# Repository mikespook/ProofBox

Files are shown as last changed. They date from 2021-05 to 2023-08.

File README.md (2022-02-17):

# TinyProofBox

An Arduino Nano based, (TODO: TinyGo implemented) sourdough proof box with LCD display

# Tools

[FreeCAD][freecad]
[KiCAD][kicad]
[Arduino IDE][ide]
TODO: [TinyGo][tinygo]

# Parts

[Arduino Nano][nano]
[DHT11][dht11] sensor
[LCD1602][lcd1602] with I2C adaptor
2 channel relay module
12V 40W Heater (diameter: 6mm, length: 20mm)
12V 4010 cooling fan
Heat sink (length: 36mm, height: 36mm, width: 35)
Prototype board (length: 70mm, width: 50mm)

[freecad]: https://www.freecadweb.org
[kicad]: https://www.kicad.org
[tinygo]: https://tinygo.org
[dht11]: https://create.arduino.cc/projecthub/search?q=DHT11
[lcd1602]: https://create.arduino.cc/projecthub/search?q=lcd1602+i2c
[nano]: https://www.arduino.cc/en/pmwiki.php?n=Main/ArduinoBoardNano
[ide]: https://www.arduino.cc/en/software

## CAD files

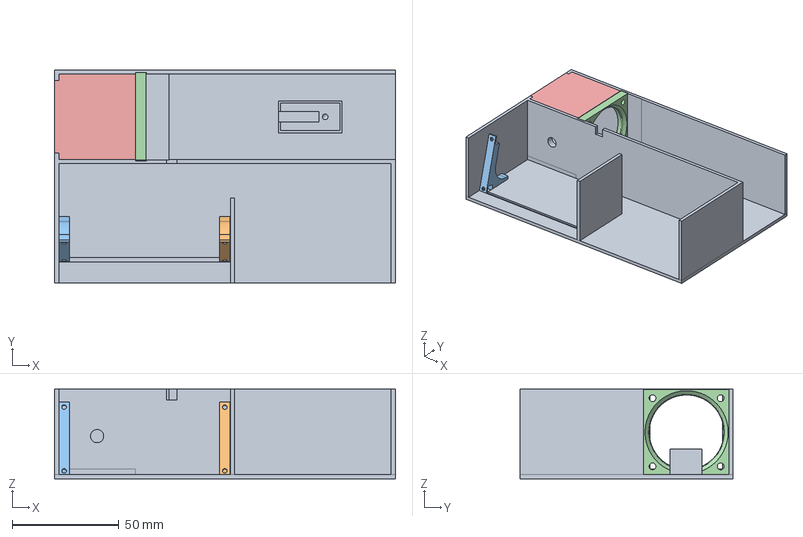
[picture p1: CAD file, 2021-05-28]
FreeCAD/ProofBox-assembled.FCStd
160.0 x 100.0 x 42.0 mm
ProofBox-parts_Base_001
ProofBox-parts_LCD stand_002
ProofBox-parts_LCD stand_001
ProofBox-parts_Fan holder_001
ProofBox-parts_Heat sink cover_001

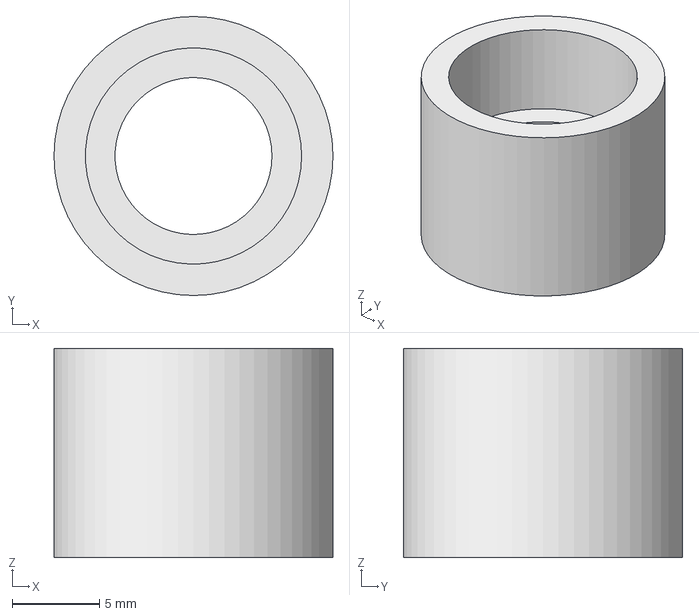
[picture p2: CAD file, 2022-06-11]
FreeCAD/ProofBox-parts.FCStd
16.0 x 16.0 x 12.0 mm

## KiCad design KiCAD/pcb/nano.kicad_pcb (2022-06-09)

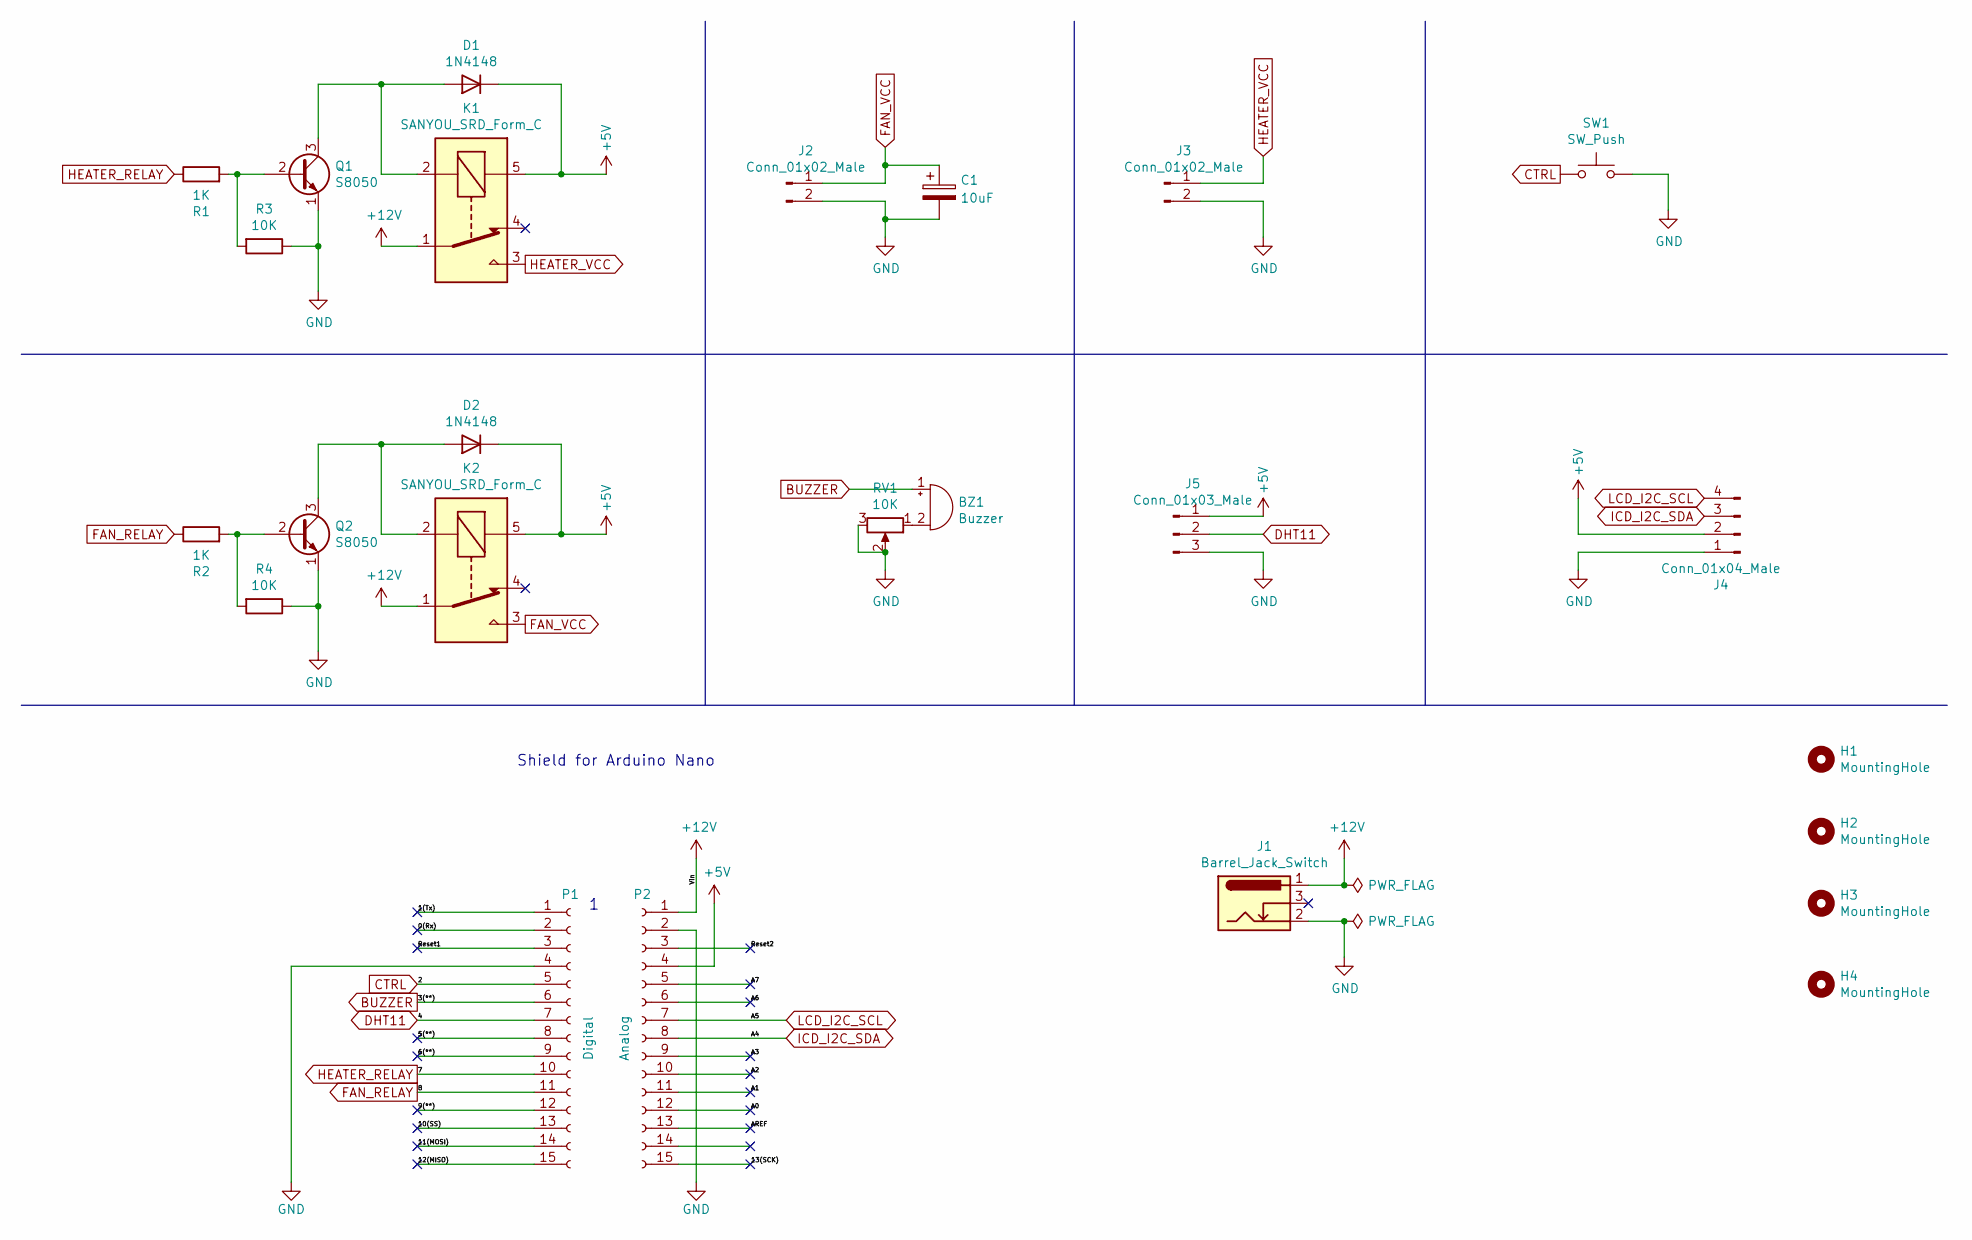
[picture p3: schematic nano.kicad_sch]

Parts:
BZ1: Buzzer; Buzzer_12x9.5RM7.6
C1: 10uF; CP_Radial_D5.0mm_P2.00mm
D1, D2: 1N4148; D_DO-35_SOD27_P7.62mm_Horizontal
H1, H2, H3, H4: MountingHole; MountingHole_2.2mm_M2
J1: Barrel_Jack_Switch; BarrelJack_Horizontal
J2, J3: Conn_01x02_Male; JST_XH_B2B-XH-AM_1x02_P2.50mm_Vertical
J4: Conn_01x04_Male; PinHeader_1x04_P2.54mm_Vertical
J5: Conn_01x03_Male; PinHeader_1x03_P2.54mm_Vertical
K1, K2: SANYOU_SRD_Form_C; Relay_SPDT_SANYOU_SRD_Series_Form_C
P1: Digital; PinSocket_1x15_P2.54mm_Vertical
P2: Analog; PinSocket_1x15_P2.54mm_Vertical
Q1, Q2: S8050; TO-92_Inline
R1, R2: 1K; R_Axial_DIN0204_L3.6mm_D1.6mm_P7.62mm_Horizontal
R3, R4: 10K; R_Axial_DIN0204_L3.6mm_D1.6mm_P7.62mm_Horizontal
RV1: 10K; Potentiometer_Runtron_RM-065_Vertical
SW1: SW_Push; SW_PUSH_6mm

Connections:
+5V: D1.1 (K), D2.1 (K), J4.2, J5.1, K1.5, K2.5, P2.4
+12V: J1.1, K1.1, K2.1, P2.1
/0(Rx): P1.2
/1(Tx): P1.1
/5(**): P1.8
/6(**): P1.9
/9(**): P1.12
/10(SS): P1.13
/11(MOSI): P1.14
/12(MISO): P1.15
/13(SCK): P2.15
/A0: P2.12
/A1: P2.11
/A2: P2.10
/A3: P2.9
/A6: P2.6
/A7: P2.5
/AREF: P2.13
/Reset1: P1.3
/Reset2: P2.3
BUZZER: BZ1.1 (-), P1.6
CTRL: P1.5, SW1.1
DHT11: J5.2, P1.7
FAN_RELAY: P1.11, R2.1
FAN_VCC: C1.1, J2.1, K2.3
GND: C1.2, J1.2, J2.2, J3.2, J4.1, J5.3, P1.4, P2.2, Q1.1 (E), Q2.1 (E), R3.1, R4.1, RV1.2, RV1.3, SW1.2
HEATER_RELAY: P1.10, R1.1
HEATER_VCC: J3.1, K1.3
ICD_I2C_SDA: J4.3, P2.8
LCD_I2C_SCL: J4.4, P2.7
unnamed: BZ1.2 (+), RV1.1
unnamed: D1.2 (A), K1.2, Q1.3 (C)
unnamed: D2.2 (A), K2.2, Q2.3 (C)
unnamed: Q1.2 (B), R1.2, R3.2
unnamed: Q2.2 (B), R2.2, R4.2

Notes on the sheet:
Shield for Arduino Nano

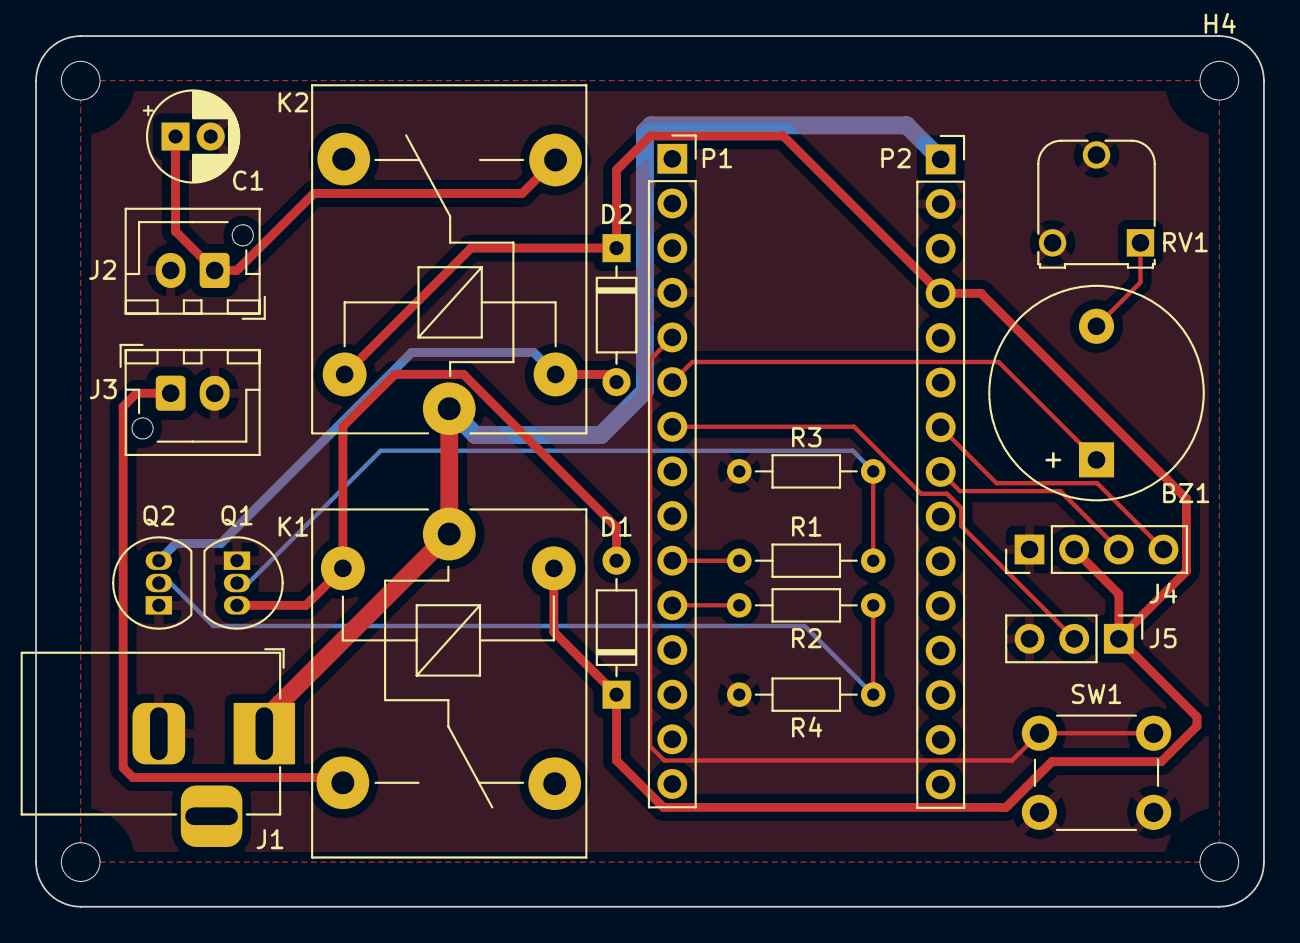
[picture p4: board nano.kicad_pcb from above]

Board: 2 copper layers, 69.8 x 49.5 mm, 25 parts (0 on the bottom side), 17 nets.

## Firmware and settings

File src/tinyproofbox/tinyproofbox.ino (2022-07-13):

#include <avr/wdt.h>

#include "ProofBox.h"
#include "Button.h"
#include "Buzzer.h"
#include "LCD.h"

#define SERIAL_SPEED 115200

float t, h;

void setup() {
	Serial.begin(SERIAL_SPEED);
	while(!Serial) {}
	Serial.println();
	Serial.print("Serial speed: ");
	Serial.println(SERIAL_SPEED);
	Button.begin();
	Buzzer.begin();
	Buzzer.on();
	LCD.begin();
	LCD.clear();
	LCD.backlight();
	delay(100);
	ProofBox.begin();
	state(ProofBox.current());
	delay(2000);
	wdt_enable(WDTO_500MS);
}

void state(int n) {
	char text[17];
	switch(n) {
		case 0:
			sprintf(text, "Off  [520.co.nz]");
			break;
		case 1:
			sprintf(text, "Starter[%d-%d%cC]", ProofBoxClass::StarterMin, ProofBoxClass::StarterMax, 0xDF);	
			break;
		case 2:
			sprintf(text, "Proof1 [%d-%d%cC]", ProofBoxClass::Proof1Min, ProofBoxClass::Proof1Max, 0xDF);	
			break;
		case 3:
			sprintf(text, "Proof2 [%d-%d%cC]", ProofBoxClass::Proof2Min, ProofBoxClass::Proof2Max, 0xDF);
			break;
	}
	LCD.output(text);
}

void loop() {
	wdt_reset();
	LCD.autoBacklight();
	if (Button.pressed()) {
		// turn on LCD
		LCD.backlight();
		uint8_t c = Button.countdown();
		if (0 == c) {
			switch(ProofBox.next()) {
				case 0:
					Buzzer.off();
					break;
				case 1:
					Buzzer.starter();
					break;
				case 2:
					Buzzer.proof1();
					break;
				case 3:
					Buzzer.proof2();
					break;
			}
			Serial.println("OK1");
			Button.ended();
			Serial.println("OK2");	
			return;
		}
		LCD.holding(c);
		return;
	}
	state(ProofBox.current());
	if (ProofBox.loop(&t, &h)) {
		LCD.output(t, h);
	} else {
		LCD.error();
	}
}

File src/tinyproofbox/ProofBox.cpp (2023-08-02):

#include "ProofBox.h"

void ProofBoxClass::begin() {
	int now = millis();
	dht = new DHT(PinDHT, DHT11);
	dht->begin();
	program = EEPROM.read(0);
	dht->readTemperature();
	dht->readHumidity();
}

bool ProofBoxClass::loop(float *t, float *h) {
	uint32_t now = millis();

	if (now < lastNow) {
		nextHeatOn = 0;
		nextHeatOff = 0;
	}
	lastNow = now;

	if (Heater.isOn()) {
		nextFanOff = now + FanTick;
	}
	// fan is controlled separatly
	if (now < nextFanOff) {
		Fan.on();
	} else if (Fan.isOn()){
		this->debug("Fan off", *t, *h);
		Fan.off();
		Heater.off();
	}

	*t = dht->readTemperature();
	*h = dht->readHumidity();
	if (isnan(*h) || isnan(*t)) {
		// failure from sensor
		this->debug("Faulty sensor", *t, *h);
		Heater.off();
		nextFanOff = now + FanTick * 10;
		nextHeatOn = now + FanTick * 30;
		nextHeatOff = now + FanTick *10;	
		return false;
	}

	if (DeathMax < (*t)) {
		this->debug("Death temperature", *t, *h);
		Heater.off();
		nextFanOff = now + FanTick * 10;
		nextHeatOn = now + FanTick * 30;
		nextHeatOff = now + FanTick *10;
		return true;
	}

	float min, max;
	switch(program) {
		case StateStarter:
			min = StarterMin;
			max = StarterMax;
			break;
		case StateProof1:
			min = Proof1Min;
			max = Proof1Max;
			break;
		case StateProof2:
			min = Proof2Min;
			max = Proof2Max;
			break;
		default:
			Heater.off();
			return true;
	}

	if (max <= (*t)) { // too high
		Heater.off();
		this->debug("Over heating", *t, *h);
		nextFanOff = now + FanTick;
		return true;
	}
	if ((min <= (*t)) && ((*t) < max)) {
		Heater.off();
		this->debug("Target reached", *t, *h);
		return true;
	}

	// off period
	if ((*t) < min && nextHeatOff <= now && Heater.isOn()) {
		Heater.off();
		this->debug("Heater off", *t, *h);
		nextHeatOn = now + offTick(*t, min);
		nextHeatOff = nextHeatOn + onTick(*t, min);
		return true;
	}

	// on period
	if ((*t) < min && nextHeatOn <= now && !Heater.isOn()) {
		Fan.on();
		delay(100);
		Heater.on();
		nextHeatOff = now + onTick(*t, min);
		nextHeatOn = nextHeatOff + offTick(*t, min);
		this->debug("Heater & fan on", *t, *h);
		return true;
	}
	return true;
}

uint32_t ProofBoxClass::onTick(float current, float target) {
	float t = target - current;
	t = t < 0 ? 0 : t;
	return round(pow(HeatOnTickBase, t / 10) * HeatOnTickAdjust);
}

uint32_t ProofBoxClass::offTick(float current, float target) {
	float t = target - current;
	t = t < 0 ? 0 : t; 
	return round(pow(HeatOffTickBase, -t / 10) * HeatOffTickAdjust);
}

uint8_t ProofBoxClass::next() {
	program ++;
	if (program > StateProof2) program = StateOff;
	EEPROM.write(0, program);
	return program;
}

void ProofBoxClass::debug(const char* msg, float t, float h) {
	debug(msg, t, h, true);
}

void ProofBoxClass::debug(const char* msg, float t, float h, bool cached) {
	if (cached) {
		if ((strcmp(msg, lastMsg) == 0) && ((t - lastT) < 0.00001) &&
				((h - lastH) < 0.00001)) {
			return;
		}
		lastT = t;
		lastH = h;
		lastMsg = msg;
	}

	char buf[16];
	sprintf(buf, "%010lu", lastNow);
	Serial.print(buf);
	Serial.print("\tHeader on at: ");
	sprintf(buf, "%010lu", nextHeatOn);
	Serial.print(buf);
	Serial.print("\tFan off at: ");
	sprintf(buf, "%010lu", nextFanOff);	
	Serial.print(buf);
	Serial.print("\tT: ");
	Serial.print(t);
	Serial.print("°C\tH: ");
	Serial.print(h);
	Serial.print("%\t");
	Serial.println(msg);
}

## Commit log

2021-05-18 added parts
    [ProofBox-parts.FCStd]
2021-05-19 update LCD stand
    [ProofBox-parts.FCStd]
2021-05-25 heat sink & fan holders
    [ProofBox-parts.FCStd]
2021-05-26 added base
    [ProofBox-parts.FCStd]
2021-05-26 added assembled
    [ProofBox-assembled.FCStd]
2021-05-27 base design
    [ProofBox-assembled.FCStd, ProofBox-parts.FCStd]
2021-05-28 restructure base
    [ProofBox-assembled.FCStd, ProofBox-parts.FCStd]
2021-06-15 init arduino firmware
2021-06-23 added PCB board
    [nano.kicad_pcb, nano.sch]
2021-06-24 reroute wires
    [nano.kicad_pcb]
2021-06-24 split PCB and prototype board
    [nano.kicad_pcb, nano.sch]
2021-06-24 prototype board
    [nano.kicad_pcb, nano.sch]
2021-06-25 wires replaned
    [nano.kicad_pcb]
2021-09-15 button and buzzer
2021-09-21 removed useless files
    [nano.kicad_pcb, nano.sch]
2022-02-17 upgrade to KiCAD 6
    [nano.kicad_pcb, nano.kicad_sch, nano.sch]
2022-02-28 fixed unlinked pads
    [nano.kicad_pcb]
2022-05-15 fixed LCD cable sequence
    [nano.kicad_pcb, nano.kicad_sch]
2022-05-15 PCB rearranged
    [nano.kicad_pcb, nano.kicad_sch]
2022-05-28 update 3D print housing
    [ProofBox-parts.FCStd]
2022-06-01 added stands
    [ProofBox-parts.FCStd]
2022-06-05 fixed logic of heating
    [ProofBox.cpp, ProofBox.h]
2022-06-06 fixed fan off logic
    [ProofBox.cpp]
2022-06-06 added button
    [ProofBox-parts.FCStd]
2022-06-09 added capacitor to fan
    [nano.kicad_pcb, nano.kicad_sch]
2022-06-11 added button holder
    [ProofBox-parts.FCStd]
2022-06-16 adjust tick of heating
2022-06-23 make sure fan off, heater off
2022-07-13 fixed watchdog reset on play sound
    [ProofBox.h, tinyproofbox.ino]
2023-08-02 21-22 is better for starter
    [nano.kicad_sch]
2024-06-27 adjusted fan time

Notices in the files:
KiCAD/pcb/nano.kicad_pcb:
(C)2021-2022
